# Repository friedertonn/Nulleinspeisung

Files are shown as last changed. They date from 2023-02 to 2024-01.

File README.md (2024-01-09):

# Nulleinspeisung

## Nutzung des überschüssigen Solarstroms zur Warmwassererzeugung
Bei diesem Projekt handelt es sich um ein Hobbyprojekt, dass keine kommerziellen Absichten verfolgt.
Die vorgestellte Schaltung besteht aus mehreren Baugruppen und hat das Ziel,
überschüssigen Solarstrom zum Betrieb eines Heizstabes in einem Warmwasserbehälter einzusetzen.
Das ist möglich, wenn folgende Voraussetzungen erfüllt sind:
- eine PV-Anlage ist vorhanden, z. B. ein Balkonkraftwerk,
- ein Stromzähler mit Infrarot-Schnittstelle, der Verbrauchswerte in kurzer Abfolge liefert,
- ein Warmwasserspeicher, der sich für die Montage eines zusätzlichen Heizstabes eignet.

## Wirkungsprinzip der Steuerung:
Der Stromzähler des Netzbetreibers liefert in kurzer Abfolge (alle 1 bis 5 Sekunden) Werte für den
aktuellen Verbrauch einer Hausinstallation mit angeschlossener PV-Anlage. 
Im Fall einer Einspeisung in das öffentliche Netz sind die Verbrauchswerte negativ.
In diesem Fall wird ein Dimmer aktiviert, der einen Heizstab in einem Warmwasserspeicher steuert.
Da die Erzeugung von Solarstrom Schwankungen unterworfen ist und andere Verbraucher im Haus aktiv/inaktiv
werden können, ist die Dimmersteuerung als Regelkreis ausgelegt:
Wenn die PV-Anlage einen Überschuss liefert, fährt der Dimmer in verschiedenen Stufen hoch, bie er im
"Arbeitsbereich" -20 Watt bis 0 Watt Gesamtbezug liegt. Bei einem Abfall des Überschusses wird der
Dimmer entsprechend abgeregelt.
Die Herausforderung besteht darin, durch eine geeignete Dimmersteuerung eine maximale Nutzung
des überschüssigen Stroms bei gleichzeitiger Vermeidung eines zusätzlichen Strombezugs zu realisieren.
Insofern stellt diese Anlage keine echte "Nulleinspeisung" dar. Eine Watt-genaue Steuerung wäre mit
einem erheblich höheren Aufwand verbunden und erfordert Verbrauchswerte im Zehntelsekunden-Takt.

## Umsetzung:
Die Steuerung erfolgt über zwei 32-bit Microcontroller ESP8266 der Firma espressif.
Der erste ESP8266 beinhaltet eine Tasmota-Software, die den
Infrarot-Lesekopf am Stromzählers liest und die Verbrauchs-/Einspeisedaten erfasst.
Der zweite ESP8266 enthält die Dimmersteuerung. 
Da dieser Prozessor im Interruptbetrieb arbeitet und die Steuerung zeitkritisch ist, 
empfiehlt sich das Zusammenlegen der Tasmota- und Dimmersoftware auf einem ESP8266 nicht.
Beide Microcontroller sind über drei Steuerleitungen miteinander verbunden.

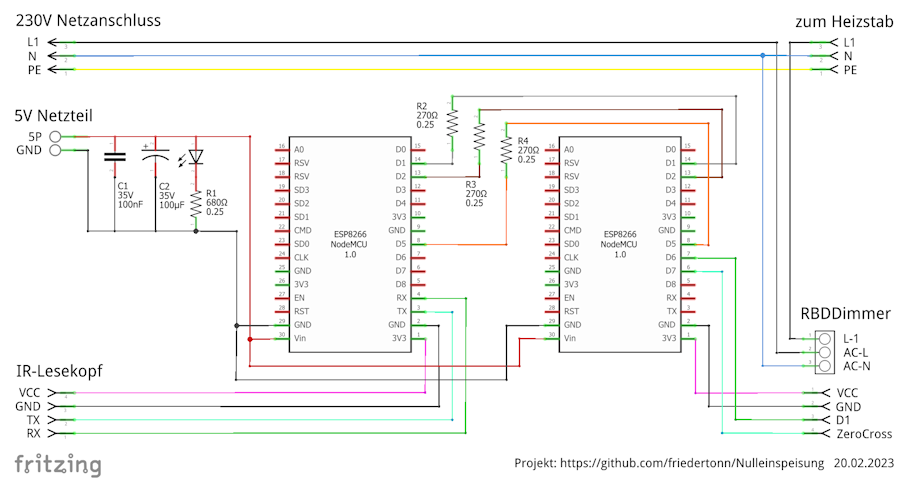
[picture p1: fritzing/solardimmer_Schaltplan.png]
Schaltplan


## ESP8266 mit Tasmota-Software:
Die aktuelle Version der Tasmota-Software steht auf der Github-Seite: https://github.com/arendst/Tasmota
Vor dem Kompilieren muss in der Datei tasmota/user_config_override.h die Scriptsteuerung aktiviert werden.
Alternativ findet sich ein compiliertes Firmware-Image **firmware.bin** der Version 12.2.0 im Unterverzeichnis tasmota.
Es kann z. B. mit dem Programm NodeMCU-PyFlasher.exe auf den ESP8266 übertragen werden.
Anschließend öffent sich auf dem ESP8266 ein lokaler WLAN-Hotspot und erfragt die WLAN-Daten des Heimnetzes.
Zum Auslesen der Verbrauchsdaten wird ein Infrarot-Lesekopf von Hichi eingesetzt. 
Er ist über zwei Steuerleitungen mit RX und TX des ESP8266 verbunden.
Die Konfiguration erfolgt über eine Scriptdatei, die auf den vorhandenen Stromzähler angepasst werden muss.
Für die Anpassung der Scriptdatei wird die Website https://tasmota.github.io/docs/Smart-Meter-Interface/ empfohlen.
Der aktuelle Script **script.txt** für meinen Stromzähler "DD3 BZ10 ETA - ODZ1" befindet sich im Unterverzeichnis tasmota.
Beim Hochladen und Ändern von Scripten auf der Tasmota-Weboberfläche ist es wichtig, 
das Häckchen bei "Script enable" zu setzen.
Wenn alles funktioniert, zeigt die Tasmota-Weboberfläche die Verbrauchsdaten an.
Über GPIO-Pins wird der aktuelle Bezug nach folgendem Schema ausgegeben:

<table style="border-collapse: separate;
  border-spacing: 0;
  padding: 5px;">
    <tbody>
    <tr style="background-color: lightblue">
        <td style="border: 1px solid #bbb; border-bottom: 1px solid #bbb; padding: 10px 15px 10px 15px;"><b>Bezug/Einspeisung</b></td>
        <td style="border: 1px solid #bbb; border-bottom: 1px solid #bbb; padding: 10px 15px 10px 15px;" colspan="2"><b> GPIO 5 (D1)</b> </td>
        <td style="border: 1px solid #bbb; border-bottom: 1px solid #bbb; padding: 10px 15px 10px 15px;" colspan="2"><b> GPIO 4 (D2)</b> </td>
        <td style="border: 1px solid #bbb; border-bottom: 1px solid #bbb; padding: 10px 15px 10px 15px;" colspan="2"><b> GPIO 14 (D5)</b> </td>
    </tr>
    <tr>
        <td style="border: 1px solid #bbb; border-bottom: 1px solid #bbb; padding: 10px 15px 10px 15px;">Bezug > 500 Watt</td>
        <td style="border: 1px solid #bbb; border-bottom: 1px solid #bbb; padding: 10px 15px 10px 15px;" colspan="2">HIGH</td>
        <td style="border: 1px solid #bbb; border-bottom: 1px solid #bbb; padding: 10px 15px 10px 15px;" colspan="2">HIGH</td>
        <td style="border: 1px solid #bbb; border-bottom: 1px solid #bbb; padding: 10px 15px 10px 15px;" colspan="2">HIGH</td>
    </tr>
    <tr>
        <td style="border: 1px solid #bbb; border-bottom: 1px solid #bbb; padding: 10px 15px 10px 15px;">500 Watt > Bezug > 100 Watt</td>
        <td style="border: 1px solid #bbb; border-bottom: 1px solid #bbb; padding: 10px 15px 10px 15px;" colspan="2">HIGH</td>
        <td style="border: 1px solid #bbb; border-bottom: 1px solid #bbb; padding: 10px 15px 10px 15px;" colspan="2">HIGH</td>
        <td style="border: 1px solid #bbb; border-bottom: 1px solid #bbb; padding: 10px 15px 10px 15px;" colspan="2">LOW</td>
    </tr>
    <tr>
        <td style="border: 1px solid #bbb; border-bottom: 1px solid #bbb; padding: 10px 15px 10px 15px;">100 Watt > Bezug > 20 Watt</td>
        <td style="border: 1px solid #bbb; border-bottom: 1px solid #bbb; padding: 10px 15px 10px 15px;" colspan="2">HIGH</td>
        <td style="border: 1px solid #bbb; border-bottom: 1px solid #bbb; padding: 10px 15px 10px 15px;" colspan="2">LOW</td>
        <td style="border: 1px solid #bbb; border-bottom: 1px solid #bbb; padding: 10px 15px 10px 15px;" colspan="2">HIGH</td>
    </tr>
    <tr>
        <td style="border: 1px solid #bbb; border-bottom: 1px solid #bbb; padding: 10px 15px 10px 15px;">20 Watt > Bezug > 0 Watt</td>
        <td style="border: 1px solid #bbb; border-bottom: 1px solid #bbb; padding: 10px 15px 10px 15px;" colspan="2">HIGH</td>
        <td style="border: 1px solid #bbb; border-bottom: 1px solid #bbb; padding: 10px 15px 10px 15px;" colspan="2">LOW</td>
        <td style="border: 1px solid #bbb; border-bottom: 1px solid #bbb; padding: 10px 15px 10px 15px;" colspan="2">LOW</td>
    </tr>
    <tr>
        <td style="border: 1px solid #bbb; border-bottom: 1px solid #bbb; padding: 10px 15px 10px 15px;">0 Watt < Einspeisung < 20 Watt</td>
        <td style="border: 1px solid #bbb; border-bottom: 1px solid #bbb; padding: 10px 15px 10px 15px;" colspan="2">LOW</td>
        <td style="border: 1px solid #bbb; border-bottom: 1px solid #bbb; padding: 10px 15px 10px 15px;" colspan="2">HIGH</td>
        <td style="border: 1px solid #bbb; border-bottom: 1px solid #bbb; padding: 10px 15px 10px 15px;" colspan="2">HIGH</td>
    </tr>
    <tr>
        <td style="border: 1px solid #bbb; border-bottom: 1px solid #bbb; padding: 10px 15px 10px 15px;">20 Watt < Einspeisung < 40 Watt</td>
        <td style="border: 1px solid #bbb; border-bottom: 1px solid #bbb; padding: 10px 15px 10px 15px;" colspan="2">LOW</td>
        <td style="border: 1px solid #bbb; border-bottom: 1px solid #bbb; padding: 10px 15px 10px 15px;" colspan="2">HIGH</td>
        <td style="border: 1px solid #bbb; border-bottom: 1px solid #bbb; padding: 10px 15px 10px 15px;" colspan="2">LOW</td>
    </tr>
    <tr>
        <td style="border: 1px solid #bbb; border-bottom: 1px solid #bbb; padding: 10px 15px 10px 15px;">40 Watt < Einspeisung < 120 Watt</td>
        <td style="border: 1px solid #bbb; border-bottom: 1px solid #bbb; padding: 10px 15px 10px 15px;" colspan="2">LOW</td>
        <td style="border: 1px solid #bbb; border-bottom: 1px solid #bbb; padding: 10px 15px 10px 15px;" colspan="2">LOW</td>
        <td style="border: 1px solid #bbb; border-bottom: 1px solid #bbb; padding: 10px 15px 10px 15px;" colspan="2">HIGH</td>
    </tr>
    <tr>
        <td style="border: 1px solid #bbb; border-bottom: 1px solid #bbb; padding: 10px 15px 10px 15px;">Einspeisung > 120 Watt</td>
        <td style="border: 1px solid #bbb; border-bottom: 1px solid #bbb; padding: 10px 15px 10px 15px;" colspan="2">LOW</td>
        <td style="border: 1px solid #bbb; border-bottom: 1px solid #bbb; padding: 10px 15px 10px 15px;" colspan="2">LOW</td>
        <td style="border: 1px solid #bbb; border-bottom: 1px solid #bbb; padding: 10px 15px 10px 15px;" colspan="2">LOW</td>
    </tr>
    </tbody>
</table>

## ESP8266 mit Dimmer-Steuerung:
Die Signale der drei GPIO-Pins werden verwendet, um den Dimmer zu steuern.
Zum Einsatz kommt ein 1-Phasen-Dimmer der Firma RobotDyn.
Der Dimmer verfügt über eine Potentialtrennung vom 230V-Bereich zum Niederspannungsbereich.
Alle Arbeiten im 230V-Bereich müssen im stromlosen Zustand und von einer Elektrofachkraft erfolgen.
An den Dimmer sollten ausschließlich ohmsche Lasten angeschlossen werden.
Es empfiehlt sich der Einbau eines EMI-Filters in die Zuleitung, um die HF-Abstrahlung zu minimieren.
Eine Bibliothek für die Dimmersteuerung ist auf Github zu finden:
https://github.com/RobotDynOfficial/RBDDimmer
Sie wurde für die Steuerung angepasst und befindet sich im Unterverzeichnis solardimmer.
Die Aufgaben der Dimmersteuerung sind:
- den Dimmer bei einem Stromüberschuss ein- und nach 5 Minuten Strombezug wieder auszuschalten,
- entsprechend des Stromüberschusses oder -bedarfes die Dimmer-Nachregelung in 3 Stufen vorzunehmen,
- bei hohem Strombedarf (> 500 Watt) den Dimmer sofort abzuschalten.

<table style="border-collapse: separate;
  border-spacing: 0;
  padding: 5px;">
    <tbody>
    <tr style="background-color: lightblue">
        <td style="border: 1px solid #bbb; border-bottom: 1px solid #bbb; padding: 10px 15px 10px 15px;" colspan="2"><b> GPIO 5 (D1)</b> </td>
        <td style="border: 1px solid #bbb; border-bottom: 1px solid #bbb; padding: 10px 15px 10px 15px;" colspan="2"><b> GPIO 4 (D2)</b> </td>
        <td style="border: 1px solid #bbb; border-bottom: 1px solid #bbb; padding: 10px 15px 10px 15px;" colspan="2"><b> GPIO 14 (D5)</b> </td>
        <td style="border: 1px solid #bbb; border-bottom: 1px solid #bbb; padding: 10px 15px 10px 15px;"><b>Dimmer-Regelung</b></td>
    </tr>
    <tr>
        <td style="border: 1px solid #bbb; border-bottom: 1px solid #bbb; padding: 10px 15px 10px 15px;" colspan="2">HIGH</td>
        <td style="border: 1px solid #bbb; border-bottom: 1px solid #bbb; padding: 10px 15px 10px 15px;" colspan="2">HIGH</td>
        <td style="border: 1px solid #bbb; border-bottom: 1px solid #bbb; padding: 10px 15px 10px 15px;" colspan="2">HIGH</td>
        <td style="border: 1px solid #bbb; border-bottom: 1px solid #bbb; padding: 10px 15px 10px 15px;">Dimmer ausschalten</td>
    </tr>
    <tr>
        <td style="border: 1px solid #bbb; border-bottom: 1px solid #bbb; padding: 10px 15px 10px 15px;" colspan="2">HIGH</td>
        <td style="border: 1px solid #bbb; border-bottom: 1px solid #bbb; padding: 10px 15px 10px 15px;" colspan="2">HIGH</td>
        <td style="border: 1px solid #bbb; border-bottom: 1px solid #bbb; padding: 10px 15px 10px 15px;" colspan="2">LOW</td>
        <td style="border: 1px solid #bbb; border-bottom: 1px solid #bbb; padding: 10px 15px 10px 15px;">-20% dimmen</td>
    </tr>
    <tr>
        <td style="border: 1px solid #bbb; border-bottom: 1px solid #bbb; padding: 10px 15px 10px 15px;" colspan="2">HIGH</td>
        <td style="border: 1px solid #bbb; border-bottom: 1px solid #bbb; padding: 10px 15px 10px 15px;" colspan="2">LOW</td>
        <td style="border: 1px solid #bbb; border-bottom: 1px solid #bbb; padding: 10px 15px 10px 15px;" colspan="2">HIGH</td>
        <td style="border: 1px solid #bbb; border-bottom: 1px solid #bbb; padding: 10px 15px 10px 15px;">-4% dimmen</td>
    </tr>
    <tr>
        <td style="border: 1px solid #bbb; border-bottom: 1px solid #bbb; padding: 10px 15px 10px 15px;" colspan="2">HIGH</td>
        <td style="border: 1px solid #bbb; border-bottom: 1px solid #bbb; padding: 10px 15px 10px 15px;" colspan="2">LOW</td>
        <td style="border: 1px solid #bbb; border-bottom: 1px solid #bbb; padding: 10px 15px 10px 15px;" colspan="2">LOW</td>
        <td style="border: 1px solid #bbb; border-bottom: 1px solid #bbb; padding: 10px 15px 10px 15px;">-1% dimmen</td>
    </tr>
    <tr>
        <td style="border: 1px solid #bbb; border-bottom: 1px solid #bbb; padding: 10px 15px 10px 15px;" colspan="2">LOW</td>
        <td style="border: 1px solid #bbb; border-bottom: 1px solid #bbb; padding: 10px 15px 10px 15px;" colspan="2">HIGH</td>
        <td style="border: 1px solid #bbb; border-bottom: 1px solid #bbb; padding: 10px 15px 10px 15px;" colspan="2">HIGH</td>
        <td style="border: 1px solid #bbb; border-bottom: 1px solid #bbb; padding: 10px 15px 10px 15px;">keine Regelung</td>
    </tr>
    <tr>
        <td style="border: 1px solid #bbb; border-bottom: 1px solid #bbb; padding: 10px 15px 10px 15px;" colspan="2">LOW</td>
        <td style="border: 1px solid #bbb; border-bottom: 1px solid #bbb; padding: 10px 15px 10px 15px;" colspan="2">HIGH</td>
        <td style="border: 1px solid #bbb; border-bottom: 1px solid #bbb; padding: 10px 15px 10px 15px;" colspan="2">LOW</td>
        <td style="border: 1px solid #bbb; border-bottom: 1px solid #bbb; padding: 10px 15px 10px 15px;">+1% dimmen</td>
    </tr>
    <tr>
        <td style="border: 1px solid #bbb; border-bottom: 1px solid #bbb; padding: 10px 15px 10px 15px;" colspan="2">LOW</td>
        <td style="border: 1px solid #bbb; border-bottom: 1px solid #bbb; padding: 10px 15px 10px 15px;" colspan="2">LOW</td>
        <td style="border: 1px solid #bbb; border-bottom: 1px solid #bbb; padding: 10px 15px 10px 15px;" colspan="2">HIGH</td>
        <td style="border: 1px solid #bbb; border-bottom: 1px solid #bbb; padding: 10px 15px 10px 15px;">+4% dimmen</td>
    </tr>
    <tr>
        <td style="border: 1px solid #bbb; border-bottom: 1px solid #bbb; padding: 10px 15px 10px 15px;" colspan="2">LOW</td>
        <td style="border: 1px solid #bbb; border-bottom: 1px solid #bbb; padding: 10px 15px 10px 15px;" colspan="2">LOW</td>
        <td style="border: 1px solid #bbb; border-bottom: 1px solid #bbb; padding: 10px 15px 10px 15px;" colspan="2">LOW</td>
        <td style="border: 1px solid #bbb; border-bottom: 1px solid #bbb; padding: 10px 15px 10px 15px;">+20% dimmen</td>
    </tr>
    </tbody>
</table>

Die dazu notwendige Software **solardimmer.ino** befindet sich ebenfalls im Unterverzeichnis solardimmer.
Das Kompilieren kann mit der Arduino-IDE erfolgen. Je nach der maximalen Leistung des angeschlossenen Verbrauchers
(bei mir 500 Watt) und dem Takt der Datenbereitstellung (bei mir sind es 2,5 Sekunden) ist das Programm 
entsprechend anzupassen.
Wenn keine Änderungen notwendig sind, kann auch die Binärdatei **solardimmer.ino.nodemcu.bin** mit dem
NodeMCU-PyFlasher.exe auf den ESP8266 übertragen werden.

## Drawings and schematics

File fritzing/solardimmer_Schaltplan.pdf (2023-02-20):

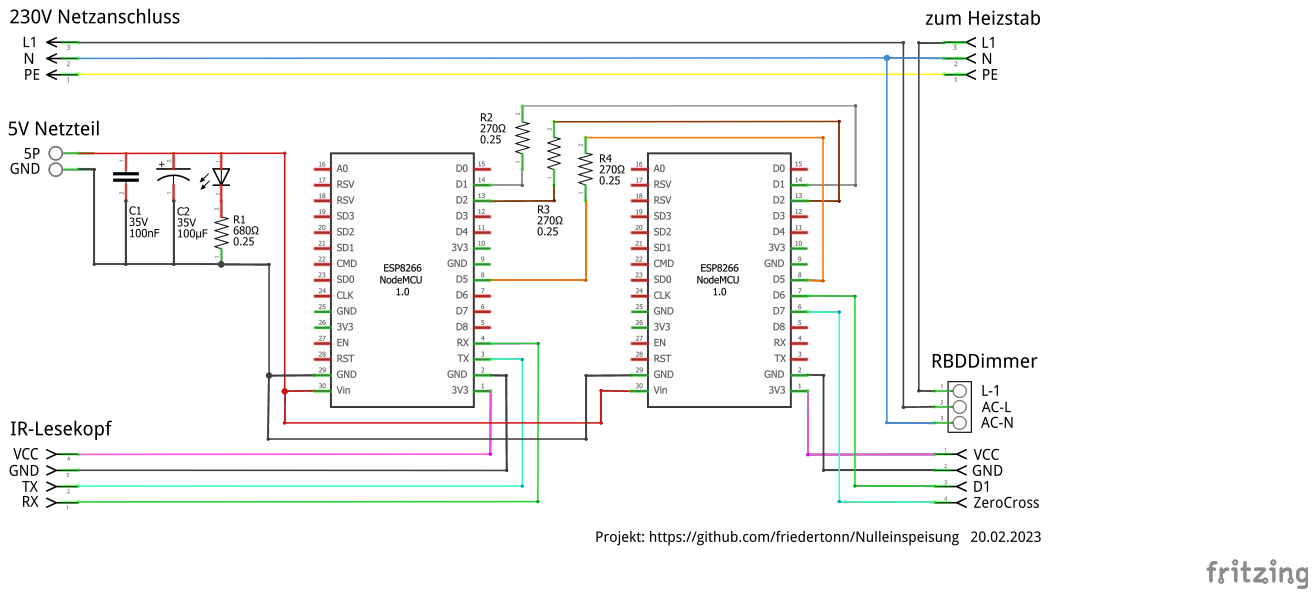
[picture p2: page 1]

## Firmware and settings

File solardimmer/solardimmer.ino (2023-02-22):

// Projekt: https://github.com/friedertonn/Nulleinspeisung
// solardimmer.ino  22.02.2023

// Betrieb des RBDdimmers über 3 Steuerleitungen (Dimmersteuerung als Regelkreis)
// D1 = GPIO 5
// D2 = GPIO 4
// D5 = GPIO 14
// +------+------+------+-----------------------------+--------------------+
// |  D5  |  D2  |  D1  | Bezug (-) / Einspeisung (+) |  Aktion            |
// +------+------+------+--------------+--------------+--------------------+
// | HIGH | HIGH | HIGH | Bezug        | < -500 Watt  | Dimmer %-Wert = 0  |
// | HIGH | HIGH |  LOW | aus dem      | < -100 Watt  | -20% dimmen        |
// | HIGH |  LOW | HIGH | öffentlichen | <  -20 Watt  |  -4% dimmen        |
// | HIGH |  LOW |  LOW | Netz         | <    0 Watt  |  -1% dimmen        |
// |  LOW | HIGH | HIGH |--------------| <   20 Watt  | keine Nachregelung |
// |  LOW | HIGH |  LOW | Einspeisung  | <   40 Watt  |  +1% dimmen        |
// |  LOW |  LOW | HIGH | in das       | <  120 Watt  |  +4% dimmen        |
// |  LOW |  LOW |  LOW | öff. Netz    | >= 120 Watt  | +20% dimmen        |
// +------+------+------+--------------|--------------+--------------------+

#include "RBDdimmer.h"

#define outputPin  12  // D6 = GPIO 12
#define zerocross  13  // D7 = GPIO 13
dimmerLamp dimmer(outputPin, zerocross);

int takt = 2500;    // alle 2500 Millisekunden gibt es einen neuen Verbrauchswert
int state = 0;      // Dimmer ON/OFF
int wert = 0;       // Dimmer-Wert in %
int maxwert = 100;  // max. Dimmer-Wert in %
int timer = 0;      // Timer für Auto-OFF nach 5 Minuten Inaktivität
int debug = 0;      // serieller Monitor: 0 = OFF, 1 = ON, 2 = alle Meldungen

void setup() {
  pinMode(5, INPUT_PULLUP);   // D1
  pinMode(4, INPUT_PULLUP);   // D2
  pinMode(14, INPUT_PULLUP);  // D5
  if (debug > 0) Serial.begin(115200);
  dimmer.begin(NORMAL_MODE, OFF);
  dimmer.setPower(wert);
  delay(500);
}

void loop() 
{
  int pin1 = digitalRead(5);   // D1
  int pin2 = digitalRead(4);   // D2
  int pin5 = digitalRead(14);  // D5
  if (debug > 1) {
    Serial.print("D5/D2/D1="); Serial.print(pin5); 
    Serial.print("/"); Serial.print(pin2);
    Serial.print("/"); Serial.print(pin1); Serial.print("  ");
  }

  if ((pin5 == 1) && (pin2 == 1) && (pin1 == 1)) wert = 0;
  if ((pin5 == 1) && (pin2 == 1) && (pin1 == 0)) wert -= 20;
  if ((pin5 == 1) && (pin2 == 0) && (pin1 == 1)) wert -= 4;
  if ((pin5 == 1) && (pin2 == 0) && (pin1 == 0)) wert -= 1;
  if ((pin5 == 0) && (pin2 == 1) && (pin1 == 0)) wert += 1;
  if ((pin5 == 0) && (pin2 == 0) && (pin1 == 1)) wert += 4;
  if ((pin5 == 0) && (pin2 == 0) && (pin1 == 0)) wert += 20;
  if (wert < 0) wert = 0;
  if (wert > maxwert) wert = maxwert;
  
  if ((state == 0) && (wert > 0)) {  // Dimmer einschalten, wenn eine Einspeisung erfolgt
    state = 1;
    dimmer.setState(ON);
  }

  if ((state == 1) && (wert <= 0)) timer++;  // Dimmer nach 5 Minuten Inaktivität ausschalten
  else timer = 0;
  if (timer > (300000 / (takt + 100))) {
    timer = 0;
    state = 0;
    dimmer.setState(OFF);
  }
  
  if (state == 1) dimmer.setPower(wert);  // Dimmer einstellen: setPower(0%-100%)
  if (debug > 0) {
    Serial.print("Status="); Serial.print(state);  
    Serial.print("  %-Wert="); Serial.print(wert);  
    Serial.print("  Timer="); Serial.println(timer);  
  }
  delay(takt + 100);
}

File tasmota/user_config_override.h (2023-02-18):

/*
  user_config_override.h - user configuration overrides my_user_config.h for Tasmota

  Copyright (C) 2021  Theo Arends

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
  You should have received a copy of the GNU General Public License
  along with this program.  If not, see <http://www.gnu.org/licenses/>.
*/

#ifndef _USER_CONFIG_OVERRIDE_H_
#define _USER_CONFIG_OVERRIDE_H_

/*****************************************************************************************************\
 * USAGE:
 *   To modify the stock configuration without changing the my_user_config.h file:
 *   (1) copy this file to "user_config_override.h" (It will be ignored by Git)
 *   (2) define your own settings below
 *
 ******************************************************************************************************
 * ATTENTION:
 *   - Changes to SECTION1 PARAMETER defines will only override flash settings if you change define CFG_HOLDER.
 *   - Expect compiler warnings when no ifdef/undef/endif sequence is used.
 *   - You still need to update my_user_config.h for major define USE_MQTT_TLS.
 *   - All parameters can be persistent changed online using commands via MQTT, WebConsole or Serial.
\*****************************************************************************************************/

/*
Examples :

// -- Master parameter control --------------------
#undef  CFG_HOLDER
#define CFG_HOLDER        4617                   // [Reset 1] Change this value to load SECTION1 configuration parameters to flash

// -- Setup your own Wifi settings  ---------------
#undef  STA_SSID1
#define STA_SSID1         "YourSSID"             // [Ssid1] Wifi SSID

#undef  STA_PASS1
#define STA_PASS1         "YourWifiPassword"     // [Password1] Wifi password

// -- Setup your own MQTT settings  ---------------
#undef  MQTT_HOST
#define MQTT_HOST         "your-mqtt-server.com" // [MqttHost]

#undef  MQTT_PORT
#define MQTT_PORT         1883                   // [MqttPort] MQTT port (10123 on CloudMQTT)

#undef  MQTT_USER
#define MQTT_USER         "YourMqttUser"         // [MqttUser] Optional user

#undef  MQTT_PASS
#define MQTT_PASS         "YourMqttPass"         // [MqttPassword] Optional password

// You might even pass some parameters from the command line ----------------------------
// Ie:  export PLATFORMIO_BUILD_FLAGS='-DUSE_CONFIG_OVERRIDE -DMY_IP="192.168.1.99" -DMY_GW="192.168.1.1" -DMY_DNS="192.168.1.1"'

#ifdef MY_IP
#undef  WIFI_IP_ADDRESS
#define WIFI_IP_ADDRESS     MY_IP                // Set to 0.0.0.0 for using DHCP or enter a static IP address
#endif

#ifdef MY_GW
#undef  WIFI_GATEWAY
#define WIFI_GATEWAY        MY_GW                // if not using DHCP set Gateway IP address
#endif

#ifdef MY_DNS
#undef  WIFI_DNS
#define WIFI_DNS            MY_DNS               // If not using DHCP set DNS IP address (might be equal to WIFI_GATEWAY)
#endif

#ifdef MY_DNS2
#undef  WIFI_DNS2
#define WIFI_DNS2           MY_DNS2              // If not using DHCP set DNS IP address (might be equal to WIFI_GATEWAY)
#endif

// !!! Remember that your changes GOES AT THE BOTTOM OF THIS FILE right before the last #endif !!!
*/

#ifndef USE_SCRIPT
#define USE_SCRIPT
#endif
#ifndef USE_SML_M
#define USE_SML_M
#endif
#ifdef USE_RULES
#undef USE_RULES
#endif

#endif  // _USER_CONFIG_OVERRIDE_H_

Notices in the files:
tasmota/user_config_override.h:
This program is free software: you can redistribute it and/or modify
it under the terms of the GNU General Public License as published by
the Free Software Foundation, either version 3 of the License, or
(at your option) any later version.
